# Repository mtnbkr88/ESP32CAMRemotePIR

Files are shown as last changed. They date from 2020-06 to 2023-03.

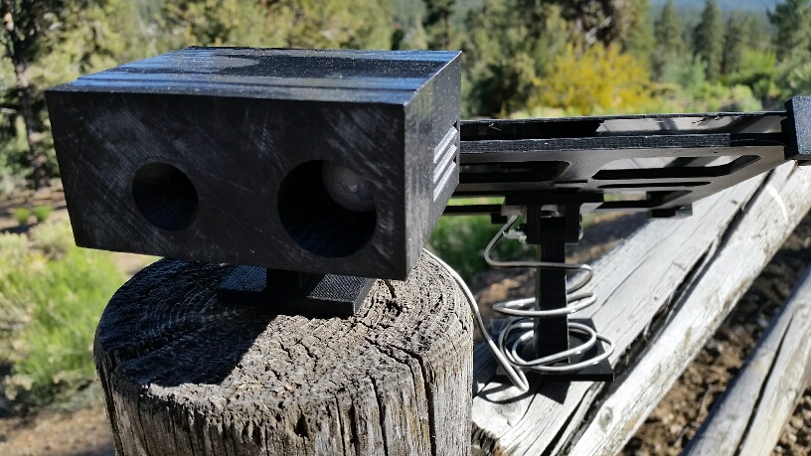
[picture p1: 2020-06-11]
ECRP_Enclosure.jpg

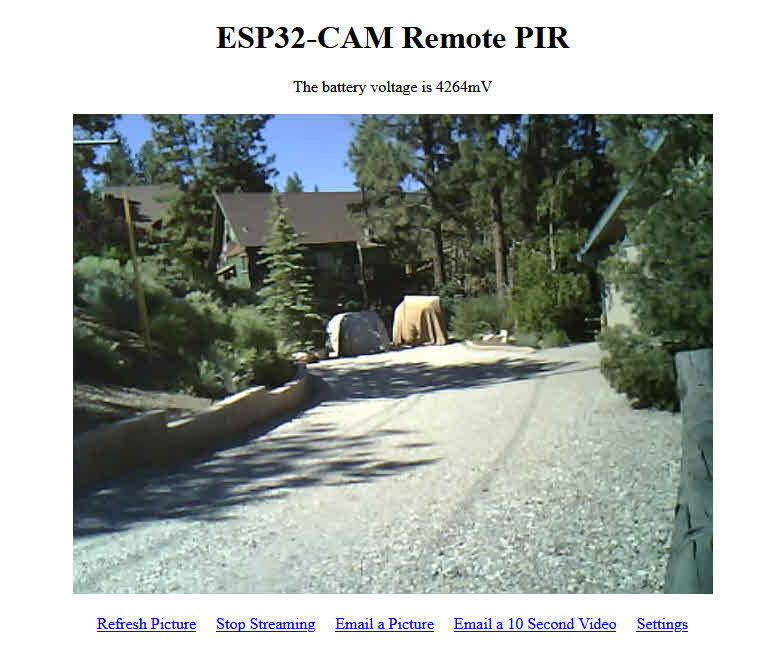
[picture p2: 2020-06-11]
ECRP_Main.jpg

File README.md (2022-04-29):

# ESP32-CAM_Remote_PIR

ESP32-CAM Remote PIR Solar Powered Picture/Video Emailer

04/28/2022 Ed Williams 

This ESP32-CAM Remote PIR can work independent or in conjunction with the ESP32-CAM Video 
Recorder I also posted in github. This ESP32-CAM Remote PIR has the following capabilities:
  - Wake from PIR and do the following:
    - Optionally send a remote trigger to an ESP32-CAM Video Recorder with the following options:
      - Take a picture.
      - Take a picture and email it.
      - Make a video.
      - Make a video and send an email with name of video.   
    - Optionally email up to 6 pictures or a 10 second AVI video.
    - Go to deep sleep.
  - Wake from a time trigger and do the following:
    - Optionally email one picture.
    - Run a webserver for 10 minutes with the following options:
      - Refresh image.
      - Start/Stop a video stream
      - Email a picture or a 10 second video.
      - Access settings.
  - Firmware updates Over-The-Air.
  - No SD card required.
  - Solar powered using a single 18650 battery per the attached schematic.
  - Battery voltage indicator is connected to GPIO12.
  - PIR motion sensor is connected to GPIO13.
  - Pictures are JPG and videos are AVI.
  - Uses a simple email utility I enhanced to send buffers or files which embedded in this
    sketch and is also now found on github. 

See ECRP_Schematic.jpg for a picture of the wiring.

Used pinMode(GPIO_NUM_13, INPUT_PULLDOWN) in the setup to pull the pin low. Now when 
motion is detected, GPIO13 will be pulled high, otherwise it will be low.

ECRP_Main.jpg shows the main screen for the ESP32-CAM Remote PIR web site.

ECRP_Settings.jpg shows the settings page.

I 3D printed an enclosure and bracket for holding the solar panel. ECRP_Enclosure.jpg 
shows the completed project.

The Default Partition Scheme must be used for compiling so OTA can work.

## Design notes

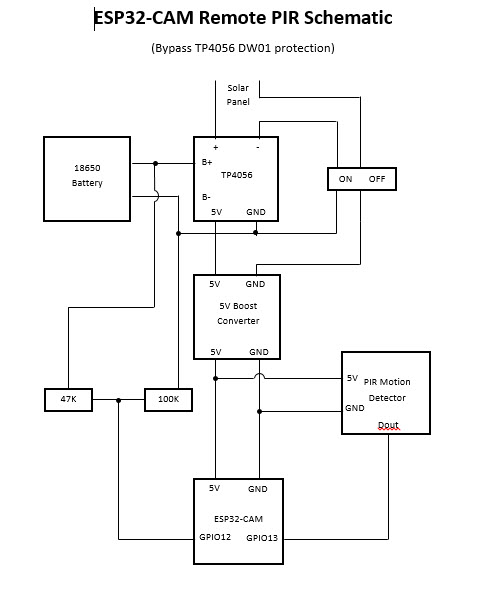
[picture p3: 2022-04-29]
ECRP_Schematic.jpg

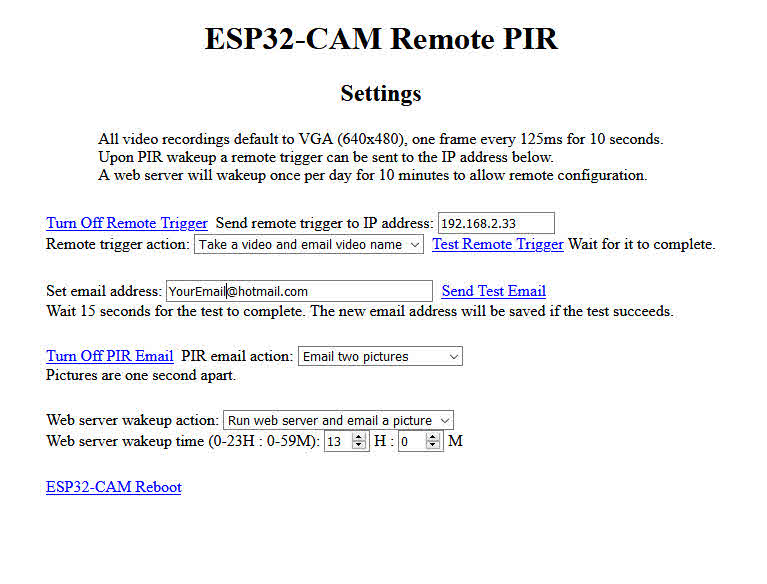
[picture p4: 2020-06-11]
ECRP_Settings.jpg

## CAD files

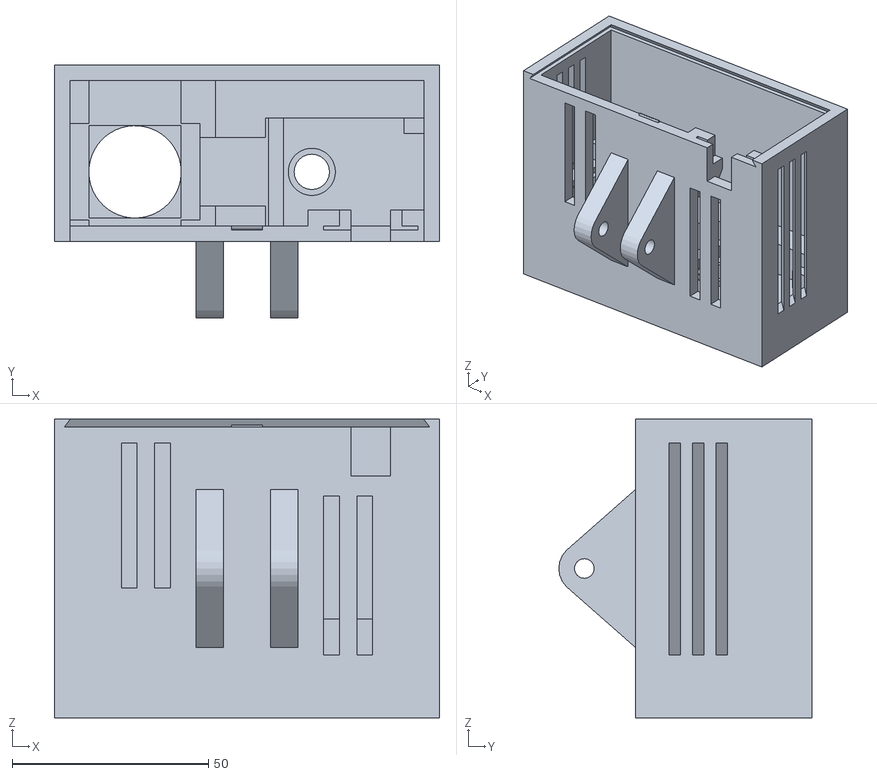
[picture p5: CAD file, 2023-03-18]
ESP32CAM_Box_PIR_Battery.stl
98.0 x 64.5 x 76.0

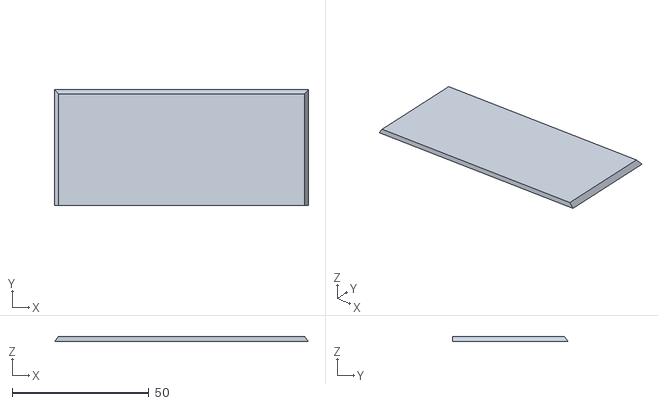
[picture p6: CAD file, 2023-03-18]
ESP32CAM_Box_PIR_Battery_Cover.stl
92.8 x 42.2 x 2.00

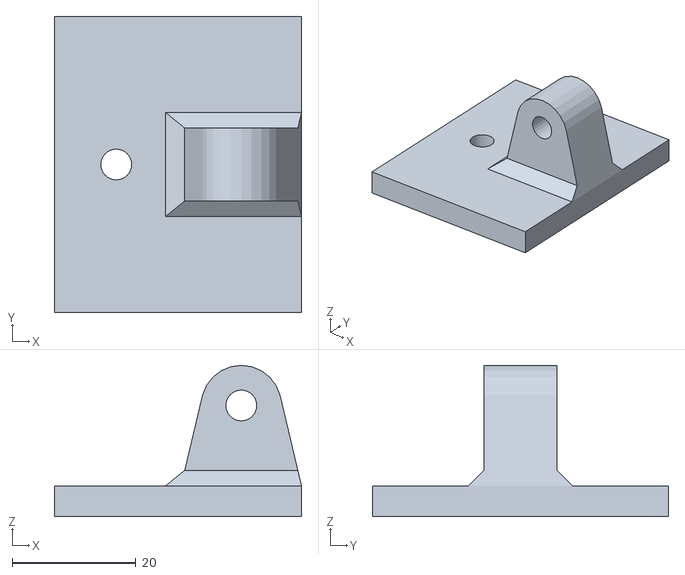
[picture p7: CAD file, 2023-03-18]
ESP32CAM_Box_PIR_Battery_Base.stl
40.0 x 48.0 x 24.5

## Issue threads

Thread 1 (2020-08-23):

webserver wake up time setup  issue

mrmate2, 2020-08-23:
Good day, many thanks for such usefull application.
For testing purposes I am running esp32cam from power adapter, no battery yet.
I am not able to adjust webserver wake up time, its always 99h99m. figures are changing,but immediately they revert to 99h99m
By the way, what is the practical use of such webserver behavior,to save battery power?

mtnbkr88, 2020-08-24:
Hi mrmate2,
I'm glad you find my application useful. My code is out there as a starting point for anybody to modify to their hearts content.

I have not had any issues with any of my four ESP32CAM boards keeping the set wake up time. Here are a few things for you to look at. 1) I use Windows 10 and Firefox browser to access my ESP32CAMs. I have not tried any other browsers. If you are not using Firefox, maybe your browser is not communicating the wake up in a way the webserver on the ESP32CAM expects. Are you seeing the confirmation popup that the wake up time was changed and does it have the correct value? 2) The subroutine where this is handled is called settings_handler. Put some Serial.println statements in there to verify the new wake up time info is getting back to the ESP32CAM. 3) Is it saving other values you are setting? 4) On line 93 of the code the default initial value for the wake up time is set to 1300 (1 pm) Pacific Time in the US. Do you see this initial time after a fresh firmware upload? If not, clear the flash to remove any leftovers from other firmware uploads before doing this firmware upload so the default initial values get loaded.

My ESP32CAMs each run off of one 18650 battery that is charged with a small solar panel and they are placed around my property. They are coded to deep sleep and wake only if the attached PIR detects motion or at the one specified wake up time so I can do maintenance like looking at what it sees or remotely uploading new firmware. This behavior is necessary to save battery power. If you don't need this behavior, change your copy of the code so it never times out to go to deep sleep.

Feel free to download and modify your own copy of this code any way you want, but please don't modify my code here (I'm not sure if you can or can't). I'm using this repository as a place to store my own code and to share it with others who might be interested in a starting point for their projects.

Thanks and good luck.

mrmate2, 2020-08-24:
Appreciate for Your detailed reply.
As per yoyr advise, I cleared the flash to remove any leftovers from other firmware uploads before doing this firmware upload so the default initial values get loaded, and now all is fine!!! I can set time for this option without issues.
Would like to ask You additional questions:
1) in what line and which parametr exactly do I have to change in order to set different timezone?
2) )in what line and which parametr exactly do I have to change in order to cancel deepsleep and to enable webserver run constantly?
Many thanks for Your replies and patience.
Best regards from Ukraine.

mtnbkr88, 2020-08-24:
1) The timezone is set with the TZ_INFO constant on line 42. Since you are in Ukraine I'm going to guess you change "PST8PDT,M3.2.0/2:00:00,M11.1.0/2:00:00" to something like "EET-2EEST,M3.5.0/3:00:00,M10.5.0/4:00:00".

2) In the loop() subroutine, comment out lines 2752-2754 so do_deep_sleep() is never called.

mrmate2, 2020-08-24:
Great! code in line 42 changed.
Remaining 1 step for me to be happy,but while compilation I am getting first error:
                               expected unqualified-id befofe "if"
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

mtnbkr88, 2020-08-24:
You commented out only two lines of the if statement. You need to comment out the third line with the curly bracket to hide the whole if statement.

mrmate2, 2020-08-24:
Yes, You are  right. noticed the same and updated my previous post few minutes fefore Your kind reply.
Now testing how all works.
Many thanks again!! All the best!

mrmate2, 2020-08-24:
Unfortunately,after modifying timezone settings and disabling deepsleep, all functions are working as usuall, exept photo/video alert on PIR motion detected. It is not a surprise due to :

>  Upon start this sketch will check if start was from a PIR signal or the deep
 * timer/power on/reset).
 *
 * If wakeup was from the PIR this sketch will send a remote trigger command to the
 * remoteTriggerIP then, based on settings, take and email pictures or take and
 * email a short video. Then it will go into a deep sleep.
 * If wakeup was from the deep sleep timer/power on/reset then start a web server
 * for 10 minutes to allow changing configuration settings or update firmware.
 * Then it will go into a deep sleep.

so it means : no deep sleep-no wake up and PIR alert....
Seems I will undo my changes in the code and use original version, as absence of PIR alert makes camera no more usefull as security detection device.
Luckily, https://github.com/mtnbkr88/ESP32CAMVideoRecorder is nearby!
Apprreciate Your work done, time spent and advices given!

mtnbkr88, 2020-08-24:
The ESP32CAMRemotePIR code is for an ESP32CAM running off of solar power so it sleeps most of the time. The ESP32CAMVideoRecorder code is for an ESP32CAM that is plugged in all the time, so that is the better choice for you. It's web server will always be on. Don't forget to configure its network, email and timezone info for you and clear your flash before putting this new image on. Note: the ESP32CAMVideoRecorder requires a mini SD card (any size) so it has a place to store pictures and videos. You will be able to view, download or delete these through the web site.

Closed 2020-08-24.

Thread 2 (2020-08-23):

send photo/video to Telegram messenger instead of emailing

mrmate2, 2020-08-23:
Dear author, is it difficuilt for  You to apply such functionality: send photo/video to Telegram messenger instead of emailing or parallel with emailing?
Many thanks in advance!

mtnbkr88, 2020-08-24:
I don't know what a Telegram messenger is, but if its something that can be reached through the internet, then I expect it can be done. Aside from the ESP32CAMs often failing to start the camera when its hot outside, I've got these things working good enough to meet my needs and I've moved on to other things. You are free to download code and add this functionality if you want. It would be a good learning experience for you. That's how I learned. I started with something that was close to what I wanted. I figured out how it worked, then I modified it to do what I wanted.

Good Luck and have fun. These ESP32CAMs are for fun and entertainment. They are too flaky to be used for anything critical.

mrmate2, 2020-08-24:
>  These ESP32CAMs are for fun and entertainment. They are too flaky to be used for anything critical.

That is completely true!!!!!

Closed 2020-08-24.

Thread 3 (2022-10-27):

Power consumption and safety

Patsjemoe, 2022-10-27:
Hi,
Interesting article.
1) have you measured power consumption of the total/how long does your battery lasts ? I have just started a similar project, and seems to drain the battery fast, even when putting esp32 in deep sleep. I suspect the dc dc , but need to check.
2) in your battery schematic, you bypass the dw01 protection ...why would you do that , you create a risk to blow up the battery..?
Thanks in advance
Regards
Ludo

mtnbkr88, 2022-10-27:
Hi Ludo,

1. Yes, the DC-DC boost converter I use does have a 3mA draw when the PIR is in its monitoring mode and ESP32 is in deep sleep. My setup will go a few days with no sun before the battery runs out which has not been an issue since I always have lots of sun.

2. If the dw01 protection is in circuit, when I switch on the power the dw01 thinks there's an issue and it shuts off the output. Then I have to temporarily short the battery negative to the dw01 negative to make it work. I'm not willing to deal with that so I bypass the dw01. I'm not worried about blowing up the battery. Feel free to wire that part to include the dw01 protection in your circuit. Hopefully you'll have better luck with it starting correctly. It's possible that newer TP4056 boards have resolved the shutoff on power on issue.

My setup has been working fine for years. Thanks for your interest.

Ed

mtnbkr88, 2022-10-28:
I used this one: https://www.ebay.com/itm/401149613381

-------- Original message --------
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

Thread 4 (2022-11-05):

Compilation error : 'ADC2_GPIO12_CHANNEL' was not declared in this scope

Patsjemoe, 2022-11-05:
Hi,
When compiling, I get following error :
'ADC2_GPIO12_CHANNEL' was not declared in this scope
   adc2_config_channel_atten(ADC2_GPIO12_CHANNEL, ADC_ATTEN_11db);
Any suggestions ?
regards
Ludo

Patsjemoe, 2022-11-05:
Hi Ed,
In the comiler, it suggested to use ADC2_CHANNEL_9 instead of ADC2_GPIO12_CHANNEL....using this, the compile error disappeared, but now the camera does not initialize.
E (3057) ledc: ledc_stop(661): LEDC is not initialized
E (3097) camera: Camera probe failed with error 0x105(ESP_ERR_NOT_FOUND)
Camera init failed with error 0x105, trying again...E (3197) gpio: gpio_install_isr_service(449): GPIO isr service already installed
It seems difficult to find information on which channel to use for ESP32CAM. The only info I found was channel 5, but then it give a fatal core error.
Any suggestions ?
Regards
Ludo

mtnbkr88, 2022-11-05:
Hi Ludo,
My research says ADC2_GPIO12_CHANNEL is defined in soc/adc_channel.h which my Arduino environment appears to be finding. In adc_channel.h is:
#define ADC2_GPIO12_CHANNEL     ADC2_CHANNEL_5
You didn't tell me the fatal error that gives.
The program I posted compiles and works fine in my environment which is Arduino 1.8.15 and in the Boards Manager I'm using esp32 version 1.0.2 (not any of the newer versions). Try that configuration and let me know if it works.

Patsjemoe, 2022-11-05:
Hi Ed,
Thank you for your feedback.
 I do not find adc_channel.h in your file as #include.... Shouldn't that
be? This may be the reason of my first error...?
I will retry tomorrow and confirm error.
Regards
Ludo

Op za 5 nov. 2022 21:54 schreef mtnbkr88 ***@***.***>:

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

mtnbkr88, 2022-11-06:
Hi Ludo,
I did not explicitly include adc_channel.h. The .ino file I uploaded is the file I used. I think the esp32 v1.0.2 configuration I use as described above automatically pulls in ADC2_GPIO2_CHANNEL. Other esp32 versions or other Arduino versions may behave differently.
Ed

Patsjemoe, 2022-11-06:
Hi Ed,
Including soc/adc_channel  no longer gives an error, it compiles fine.
It starts up , connects to internet, wakes up bij timer ,until config
camera..then it goes wrong.

Loading initial values from EEPROM

Remote trigger set to 0

Remote IP address set to 0.0.0.0

Email address set to ***@***.***

Motion email action set to 1

Wakeup Time set to 11300

Wakeup caused by timer, power on, or reset - starting config web server

 Before startWebServer  Free Heap: 202992

 After startWebServer  Free Heap: 180764

config camera

 Before camera init  Free Heap: 180564

*E (3132) ledc: ledc_stop(661): LEDC is not initialized
*

*Pic, len=10346
*

*Guru Meditation Error: Core  1 panic'ed (LoadProhibited). Exception
was unhandled.*

Core  1 register dump:

PC      : 0x400d349f  PS      : 0x00060c30  A0      : 0x800d3460  A1
   : 0x3ffb20d0

A2      : 0x3ffc4ad8  A3      : 0x3ffc4994  A4      : 0xfffffffe  A5
   : 0x00000000

A6      : 0x3ffcf220  A7      : 0x3ffc498c  A8      : 0x3ffc498c  A9
   : 0x3ffb2090

A10     : 0x00000021  A11     : 0x00000000  A12     : 0x00000000  A13
   : 0x00000000

A14     : 0x3ffcf220  A15     : 0x00000000  SAR     : 0x00000007
EXCCAUSE: 0x0000001c

EXCVADDR: 0x00000002  LBEG    : 0x4008d5d5  LEND    : 0x4008d5e5
LCOUNT  : 0xfffffffe

Backtrace:0x400d349c:0x3ffb20d00x400d345d:0x3ffb2100
0x400d473f:0x3ffb2120 0x400d5a99:0x3ffb21b0 0x400d63a1:0x3ffb27b0
0x400d6e58:0x3ffb27d0 0x400df8ae:0x3ffb2820

note : with esp32 version 1.0.2 installed, I get following error :
Error resolving FQBN: getting build properties for board
esp32:esp32:esp32cam: invalid option 'CPUFreq'

Compilation error: Error resolving FQBN: getting build properties for board
esp32:esp32:esp32cam: invalid option 'CPUFreq'
Compilation error: Error resolving FQBN: getting build properties for board
esp32:esp32:esp32cam: invalid option 'CPUFreq'

regards
Ludo
I:\arduino\hardware\espressif\esp32\sketches\esp32camPIRemail\esp32camPIRemail.ino:
In function 'esp_err_t start_avi_buf()':
I:\arduino\hardware\espressif\esp32\sketches\esp32camPIRemail\esp32camPIRemail.ino:904:1:
warning: no return statement in function returning non-void [-Wreturn-type]
 } // end of start avi

Compilation error: Error resolving FQBN: getting build properties for board
esp32:esp32:esp32cam: invalid option 'CPUFreq'

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

mtnbkr88, 2022-11-06:
Ludo,
There is definitely a difference between your environment and mine. I had trouble with ESP32 versions higher than 1.0.2 so I didn't use them. I used ESP32-CAM boards based on AI thinker. Here are my settings in Arduino.

    - Go to Tools->Board->Boards Manager....
    - Search for ESP32 and press Install button for "ESP32 by Espressif Systems". (Use version 1.0.2)
    - Go to Tools->Board->ESP32 Wrover Module.
    - Upload Speed "921600"
    - Flash Frequency "80MHz"
    - Flash Mode "QIO"
    - Partition Scheme "Default 4MB with spiffs" or "Default 4MB with ffat"
      either one should support firmware builds up to 1.3MB and OTA
    - Core Debug Level "None"
    - Port "COM6" - can only set this after FTDI adapter is plugged in USB
      (When using the serial monitor, set its baud rate to 115200)

mtnbkr88, 2022-11-06:
I also installed an ESP Exception Decoder. This will allow you to find the line in your code that is giving an exception.
Find and download the EspExceptionDecoder.jar from the internet and install as follows:
    - Create folder C:\Users\Owner\Documents\Arduino\tools\EspExceptionDecoder\tool.
    - Place EspExceptionDecoder.jar in it.
    - Restart Arduino IDE. ESP Exception Decoder can now be found under Tools.
If an exception occurs, copy the trace dump and paste it into the ESP Exception Decoder window and it
will give more clues for what went wrong.

mtnbkr88, 2022-11-06:
If you haven't already, you might want to install a basic ESP32 camera example test program from the examples area of Arduino or EspressIf to be sure your board and camera work correctly before trying my program which is more complex.

Patsjemoe, 2022-11-06:
Hi Ed,
I had done this already, but could not use it yet due to the errors.
I tried to install it in version 2.0, but it only works with 1.18 due to
java....
regards
Ludo

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

Patsjemoe, 2022-11-06:
Hi Ed,
Here I used ESP32cam...changed to ESP32 wrover module.
Partition scheme in version 1.8.15 is different : I took minimal SPIFFS,
large apps with ota...
[image: image.png]
In both your program as well as a basic esp32cam webserver, I had following
error :
xtensa-esp32-elf-g++: error: unrecognized command line option
'-mfix-esp32-psram-cache-strategy=memw'
exit status 1
Error during compilation for  board ESP32 Wrover Module
Looking further into it...
regards
Ludo

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

Patsjemoe, 2022-11-06:
Hi Ed,
I wonder if there is a conflict between different installed versions./..

regards
Ludo

On Sun, 6 Nov 2022 at 19:52, Ludo Kustermans ***@***.***>
wrote:

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

Patsjemoe, 2022-11-06:
Hi Ed,
....sorry for hte many mails....
I had installed version 1.02, but it seems you need to do also an update
....now I can select the right
Default 4MB with spiffs
Still errors....but moving forward...
regards
Ludo

On Sun, 6 Nov 2022 at 19:52, Ludo Kustermans ***@***.***>
wrote:

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

mtnbkr88, 2022-11-06:
Glad you are making progress. I don't think the example camera program worked for me the first time either. Like I said, work on getting the example camera program working. Once you get that working it should be simple to get my program working. My program uses OTA for firmware updates so you will need to choose a partition scheme that supports OTA. I don't use spiffs so your choice if you want to allocate space for spiffs.

Patsjemoe, 2022-11-07:
Hi Ed,
Did a new clean install of 1.8.15 with espressif 1.0.2, and it works
now 😀....touch wood it will
stay that way .
I must admit, when seeing soo many errors yesterday, it made me feel like
it would never work....
WIth the installation of 1.8.15, I then had also issues with my arduino 2.0
version, but it seems that the espressif board version 1.02 that I
installed, also is installed in the version 2.0...I am not sure if there is
a way to be sure the version remains only in the arduino version where you
install it....
Ludo

Op zo 6 nov. 2022 22:29 schreef mtnbkr88 ***@***.***>:

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

Patsjemoe, 2022-11-07:
Hi Ed,
From the Arduino forum I received following : (was not 100% sure...).
1.8.15 has the log4j security vulnerability; you're advised to upgrade to
1.8.19 or go back a few to before 1.8.13
Just that you know it may have an issue...
regards
Ludo

On Mon, 7 Nov 2022 at 12:07, Ludo Kustermans ***@***.***>
wrote:

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

mtnbkr88, 2022-11-07:
Hi Ludo,
I very happy to hear you got it working. I'm not losing any sleep over security vulnerabilities in my ESP32 projects. Thanks for letting me know. If you install Arduino 1.8.19 with espressif 1.0.2 and get it working please let me know.
Enjoy!
Ed

Patsjemoe, 2022-11-07:
Hi Ed,
I tested with arduino 1.8.19 and espressif 1.0.2 and it worked well.
Just 1 more question : I saw that you connect directly the output of the
pir (5V) to the esp32cam. It is difficult to find a datasheet
showing if the GPIO pins are 5V tolerant.....you never had any issue ? Or
did you get confirmation that they are 5V tolerant ?
I can also change to a 3.3V level with a transistor, levels are then
reversed....this is also OK, but have to change also the
conditional checks on the level op GPIO13 further in the program...how many
places should I find ?
regards
Ludo

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

mtnbkr88, 2022-11-07:
Hi Ludo,
Glad to hear Arduino 1.8.19 and espressif 1.0.2 are good.
I've been running my PIR setup for years and there is definitely no issue with using the 5V out from the PIR. For a while I did use a transistor between the PIR and ESP32 but it did not work well. Also, the PIR I use is HC-SR501. I had a lot of problems with false positives but after much research I found that putting a 220nF capacitor between pins 12 and 13 on the main chip as shown here (https://redfox314.tweakblogs.net/blog/16895/esp8266-and-hc-sr501-false-positives) solved it. My solar setup has been rock solid sitting on top of a fence post watching my driveway for years.
Ed

Closed 2022-11-05.

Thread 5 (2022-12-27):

time for webserver to run

Patsjemoe, 2022-12-27:
Hi Ed,
I would like the time the server runs to bring back to 1 min (or even zero to save power, and only email pictures when moving).
  if ( millis() - timeout_10min > (10 * 60 * 1000) ) {
    do_deep_sleep();

I changed it to :
  if ( millis() - timeout_10min > (1 * 60 * 1000) ) {
                                                   -- > so I expected 1 min
but it does not go asleep after 1 min...
Any suggestions to what I do wrong  ?
Thanks in advance
regards
Ludo

Patsjemoe, 2022-12-27:
Hi Ed,
When I change to if ( millis() - timeout_10min > (1 * 60 * 100) ) {
...it goes asleep after 6-7 sec...which is accordingly..
Not sure why , do not understand
regards
Ludo

Patsjemoe, 2022-12-27:
Hi Ed,
I used different cams for the 2 tests, with 1 device, it works , with the other one, it is not going to sleep.....if someone understands this ?
Regards
Ludo

Patsjemoe, 2022-12-27:
Hi Ed,
You can forget the question, but want to share this issue, as it is simple, but at the same time difficult to find.
I adapted from PIR to detection when a switch opens, with a pulldown resistore external, so would be triggerd with 3V on pin 13.
When I adapted my program to 1 minute, it did not work, as there was in fact a constant trigger from the switch that was at 1 (in my application, it is pushed down to give a 0, and gives a 1 when the roof of the squirl feeding house opens, but as I was working on it, the roof was constantly open...) It works fine now, testing how long it works on battery....

mtnbkr88, 2022-12-27:
Glad you got it working for a detector for when a squirrel opens his nut house. For your first question change the math to (6 x 1000) and you'll understand. millis() gives a value in milliseconds. 1000 milliseconds is one second. So 6 x 1000 is 6 seconds.

Closed 2022-12-27.

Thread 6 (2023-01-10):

Re-wake up

Patsjemoe, 2023-01-10:
Hi Ed,
When setting  the daily  wake time to 6 seconds (save power) ,It makes a multiple wake up from 2 to 4 times. Any idea why that can be?
Regards
Ludo

mtnbkr88, 2023-01-10:
Hi Ludo,
I'm not exactly sure what you mean by setting the daily wake time to 6 seconds. If you didn't change it the wake time is one specific time of day. The deep sleep logic calculates how long from current time to the daily wake time specified in your settings and uses that to set how long to sleep. If it wakes multiple times a day there is something wrong with the logic you are using to calculate how long to sleep.
Ed

Patsjemoe, 2023-01-11:
Hi Ed,
It is the time it stays awake... 6 sec.
When it wakes up hasn't changed, 1x a day.
But it wakes up 2-4 times in a period of 1-2minutes, often it sends a photo
with the same wakeup time.
When setting time to 10 minutes, it is only once.... I wonder what triggers
this multiple wake up. Could you try yourself and see what happens?
Regards
Ludo

Op di 10 jan. 2023 22:00 schreef mtnbkr88 ***@***.***>:

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

mtnbkr88, 2023-01-11:
If it fails to get a network connection it will sleep for a second and wake to try again. If it has trouble initializing the camera which happens often with mine it will retry again up to five times. If it thinks it failed to send the email it will retry sending the email multiple times. If you are using a PIR sensor that is too sensitive it can trigger often with false alarms. Mine goes crazy when it rains. Plus I don't know how you've modified the code. There are so many areas of possible trouble that I'm afraid there isn't one specific thing I can say is causing your issue.

Mine is normally sitting on a fence at the limits of my local wifi network. It's often having problems and when I bring it in and connect it to my laptop to watch the serial monitor it works better so I'm having difficulties with its inconsistent behavior. I'm still tweaking my code trying to make it work better but it never gets better. Unfortunately these little ESP32CAMs are not very reliable and probably should be considered as toys. It is what it is.

All I can suggest is to connect it to a serial port, put lots of Serial.println statements in areas you think might be where the problem is and watch the serial monitor for a while in hopes of capturing any clues to your issue.

Sorry I can't help more.
Good Luck!

Patsjemoe, 2023-01-11:
Hi Ed,
Thank you, so these retries are normal, depending the circumstance.....this
is clear. I also understand now where the 1 sec is used for... Was
wondering...

What I also observed... when the "10 min" server is active, I do not get
reaction to my PIR... Is this normal?

FYI  : I changed my esp32cam to take an external antenna, which I need, as
it also stands away from my house... This gives better results.

Thank you for your quick reply.

Regards
Ludo

Op wo 11 jan. 2023 08:47 schreef mtnbkr88 ***@***.***>:

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

mtnbkr88, 2023-01-11:
Hi Ludo,

I put an up to 10 min wait for the PIR signal to stop when going to sleep to prevent continuous quick triggers. For me if too many emails are sent too quickly gmail locks my email account. I'm trying to prevent that. I'm sure you know you can change the code to do anything you want.

I've thought about adding an external antenna but I don't want to.

Ed

Closed 2023-01-10.

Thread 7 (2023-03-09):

cant compile

allbondy, 2023-03-09:
it is most like me
but cant work it out
help would be greatly appreciated

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

mtnbkr88, 2023-03-09:
ADC2_GPIO12_CHANNEL is defined as part of esp32 library version 1.0.2. In Arduino IDE (I'm using version 1.8.15), go into Tools->Board: "ESP32 Wrover Module"->Boards Manager... . In the search bar at the top, search for esp32. When esp32 library is found, set the version to 1.0.2 then pick Install. This should solve your issue.

Closed 2023-03-09.

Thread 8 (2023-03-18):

3D Print Enclosure

gwinterhalter, 2023-03-18:
Hi mtnbkr88

Can you add the Cad/Stl files for enclosure?

Great work on this project. Intend to build a couple.

Thanks Greg

mtnbkr88, 2023-03-18:
Done - good luck with your builds.

Closed 2023-03-18.

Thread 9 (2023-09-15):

Guru Meditation Error: Core  1 panic'ed

Patsjemoe, 2023-09-15:

Patsjemoe, 2023-09-15:
trying few more things, therefore actually closed

mtnbkr88, 2023-09-15:
Hi Ludo,

I'm still using Arduino 1.8.15 and board version 1.0.2.
Install the attached EspExceptionDecoder.jar using the instructions below. Paste the backtrace from the error in the tool and it will tell you what line in the code is giving the error and a clue as to why.
    - Create folder C:\Users\Owner\Documents\Arduino\tools\EspExceptionDecoder\tool.
    - Unzip EspExceptionDecoder.zip and place EspExceptionDecoder.jar in the directory create above.
    - Restart Arduino IDE. ESP Exception Decoder can now be found under Tools.

[EspExceptionDecoder.zip](https://github.com/mtnbkr88/ESP32CAMRemotePIR/files/12622438/EspExceptionDecoder.zip)

Patsjemoe, 2023-09-15:
Hi there,
It's been a while... 😃. Hope you are OK.
I first had put in the back trace, but took it out, because I thought it
was because for whatever reason the board version updated. Went back to a
clean 1.02.
Now I do not get the panic error anymore, but with 1.0.2 waiting in email
picture, and moving to 1.0.5, it says waiting in email picture, failed to
send, end of setup, esp ready, so it goes further.
I can go onto the server.
Trying to figure out why it does not send the mail.... Should  be OK, as I
am running 2 other birdhouses.... But it is not.
Best regards
Ludo

Op vr 15 sep. 2023 20:12 schreef mtnbkr88 ***@***.***>:

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

mtnbkr88, 2023-09-15:
Hi Ludo,
When I tried board versions higher than 1.0.2 I got errors so I just stuck with 1.0.2. Your issue is a mystery. Did you try a different board with the exact same code to verify it's not a hardware issue? Did you add any other code that is using up heap? I found that lots of heap needs to be available for network stuff to work. Maybe put some print statements that show the heap before, during, and after the email to see if its a low memory issue.

mtnbkr88, 2023-09-15:
Search for //#define DEBUG_EMAIL_PORT (around line 460 in my copy of the code), uncomment this line (remove two slashes), then recompile and run again. You should see debug info for the sending email part. Hopefully there will be a clue in there as to why the email is failing to send.

Patsjemoe, 2023-09-16:
Hi,
Thanks for yr suggestion, did not know it was in there .
Connecting: smtp.gmail.com:465
Connecting: smtp.gmail.com:465
Connecting: smtp.gmail.com:465
Connecting: smtp.gmail.com:465
Connecting: smtp.gmail.com:465
Failed to send email
It must have to do with my app password...made a new one, but still a
problem...look further.

Stil not working after a whole day, so any idea is welcome.
Had 2 other birdhouses working, nothing changed, so I am puzzled.
Since I had to change my psw, it also deletes all app psw in Google, so
made new ones..... Surprised that google has no tool to quickly check app
password...

regards
Ludo

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

mtnbkr88, 2023-09-16:
Hi Ludo,
Based on your message above it sounds like you are using an app password for sending your email which is what I had to do last year.

The output you posted shows its failing it's first connection to the gmail server. Look for the below in your code and add the lines with "//*** add for debug" in them to hopefully see why the connection is failing:

#ifdef DEBUG_EMAIL_PORT
  Serial.print(F("Connecting: "));
  Serial.print(host);
  Serial.print(":");
  Serial.println(port);
#endif
  if (!client->connect(host.c_str(), port))
  {
#ifdef DEBUG_EMAIL_PORT                  //*** add for debug
    String buffer = readClient();              //*** add for debug
    Serial.print(F("SERVER->CLIENT: "));  //*** add for debug
    Serial.println(buffer);                        //*** add for debug
#endif                                                 //*** add for debug
    return false;
  }
  String buffer = readClient();

If that doesn't work, to hopefully see what code client->connect(host.c_str(), port) is returning replace:

 if (!client->connect(host.c_str(), port))

with:

 int clientReturnCode;
 clientReturnCode = client->connect(host.c_str(), port));
 Serial.print(F("clientReturnCode: "));
 Serial.println(clientReturnCode);
 if (!clientReturnCode)

Look in https://github.com/espressif/newlib-esp32/blob/master/newlib/libc/include/sys/errno.h
to see what the clientReturnCode means.

I have had the problem where my ESP32 chips have sent too many emails to gmail and they blocked login from my ESP32 thinking it was spam. Waiting a day unblocked the account.

Below are my notes from when I had to switch to using an app password for my esp32 stuff in case it helps.

NOTE: Around 06/07/22 gmail made changes that broke my sendmail stuff. I had to do the
following to create another gmail account and use a 2-factor app password:
- Create another gmail account so if it gets messed up it doesn't screw my normal gmail
  account.
  - Go to https://www.google.com/gmail/about/.
  - Pick Create an account.
  - First: <private>, Last: ESP32, Username: <private>ESP32@gmail.com, PW: usual
  - Recovery email: <private>@gmail.com, bday, gender
- Create an App Password to use with the new gmail account.
  - Open the google account. https://myaccount.google.com/u/1/?hl=en
    (Make sure its for <private>ESP32@gmail.com and not my other gmail address.
  - In navigation panel, select Security.
  - Under "Signing in to google", select 2-Step Verification->Get started.
  - Follow prompts to complete 2-step verification.
  - Back to google account page, select Security again.
  - Under "Signing in to Google", select App Passwords.
  - Set Selected app to mail, and selected device to Other and set its name to ESP32,
    Generate. Copy the 16 char password to use as the password later: <app_pw>
- Yay, its working with <private>esp32@gmail.com and the password above. Use these
  for future emails from my esp32 chips.

Good luck!
Ed

Patsjemoe, 2023-09-17:
Hi,
You showed :
Set Selected app to mail, and selected device to Other and set its name to
ESP32,
I did not see anything to assign to mail, only to delete it.
Will check again...
Not sure how, right click?
Regards
Ludo

Op zo 17 sep. 2023 01:20 schreef mtnbkr88 ***@***.***>:

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

Patsjemoe, 2023-09-17:
Hi,
after first replacement : 5x
Connecting: smtp.gmail.com:465
SERVER->CLIENT:

after second replacement (clientReturnCode = client->connect(host.c_str(),
port);
Connecting: smtp.gmail.com:465
clientReturnCode: 0 ---> did not find this code
SERVER->CLIENT:
Regards
Ludo

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

Patsjemoe, 2023-09-17:
Hi,
I moved back (again) to 1.0.2 , and now it works again....
I am not sure what is happening, but will just be glad it works.
Still, In Gmail, I cannot select App PSW in security google login, but need
to go to 2 step verification and then go to
app.....but cannot select /assign the password to some application....I do
not have a dropdown menu. Try google to get response on this...
Thanks again for your attention and help.
regards
Ludo

On Sun, 17 Sept 2023 at 09:16, Ludo Kustermans ***@***.***>
wrote:

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

mtnbkr88, 2023-09-17:
Glad it works again. My notes are from over a year ago so its likely Google change something since then. FYI - A return code of 0 means there was no error and it should have worked correctly.

Good luck,
Ed

Closed 2023-09-15.

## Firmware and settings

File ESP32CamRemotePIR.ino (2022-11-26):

/**********************************************************************************
 * 11/25/2020 Edward Williams
 * Upon start this sketch will check if start was from a PIR signal or the deep 
 * timer/power on/reset).
 * 
 * If wakeup was from the PIR this sketch will send a remote trigger command to the 
 * remoteTriggerIP then, based on settings, take and email pictures or take and 
 * email a short video. Then it will go into a deep sleep. 
 * 
 * If wakeup was from the deep sleep timer/power on/reset then start a web server 
 * for 10 minutes to allow changing configuration settings or update firmware.
 * Then it will go into a deep sleep.
 * 
 * A battery divider circuit with a 147K and 100K resister will be attached to GPIO12
 * for battery voltage reads. A PIR detector will be attached to GPIO13 for PIR wakeup
 * from deep sleep.
 **********************************************************************************/


/**********************************************************************************
 * 03/25/2020 Edward Williams
 * This is a shell which includes an Over-The-Air firmware update web server which
 * includes the option to erase EEPROM, fixed IP address, a major fail flashing led 
 * notice with sleep reboot, time set and mount of SD card. I use this as a starting 
 * point for all my sketches. Visit the web site <IP>/updatefirmware and enter the 
 * password to upload new firmware to the ESP32. Compile using the "Default" Partition 
 * Scheme.
 **********************************************************************************/
 
// edit the below for local settings 

// wifi info
const char* ssid = "YOURSSID";
const char* password = "YOURSSIDPW";
// fixed IP info
const uint8_t IP_Address[4] = {192, 168, 2, 35};
const uint8_t IP_Gateway[4] = {192, 168, 2, 1};
const uint8_t IP_Subnet[4] = {255, 255, 255, 0};
const uint8_t IP_PrimaryDNS[4] = {8, 8, 8, 8};
const uint8_t IP_SecondaryDNS[4] = {8, 8, 4, 4};

const char* TZ_INFO = "PST8PDT,M3.2.0/2:00:00,M11.1.0/2:00:00";

const int SERVER_PORT = 80;  // port the main web server will listen on

// edit email server info for the send part, recipient address is set through Settings in the app
const char* emailhost = "smtp.gmail.com";
const int emailport = 465;
const char* emailsendaddr = "YOUREMAIL\@gmail.com";
const char* emailsendpwd = "YOUREMAILPW";
char email[40] = "YOUREMAIL\@hotmail.com";  // this can be changed through Settings in the app

const char* appName = "ESP32CamRemotePIR";
const char* appVersion = "1.0.7";
const char* firmwareUpdatePassword = "12345678";

// should not need to edit the below

#include "esp_http_server.h"
httpd_handle_t webserver_httpd = NULL;   

#include <WiFi.h>

#include "soc/soc.h"  //disable brownout problems
#include "soc/rtc_cntl_reg.h"  //disable brownout problems

#include "time.h"
#include "lwip/err.h"
#include "lwip/apps/sntp.h"
struct tm timeinfo;
time_t now;

#include <EEPROM.h>  // for erasing EEPROM ATO, assumes EEPROM is 512 bytes in size
#include <Update.h>  // for flashing new firmware

#define uS_TO_S_FACTOR 1000000LL  // Conversion factor for micro seconds to seconds
#define TIME_TO_SLEEP1S  1        // Time ESP32 will go to sleep (in seconds)

// EEPROM setup for saving values over reboots
#include <EEPROM.h>  // also used in OTA firmware update screen
#define EEPROM_READY_ADDR 0x00
const byte eeprom_ready[] = {0x52, 0x65, 0x61, 0x64, 0x79};
#define EEPROM_REMOTE_ADDR (EEPROM_READY_ADDR+sizeof(eeprom_ready))
int remoteTrigger = 0;  // <10 is off, >10 is on
#define EEPROM_REMOTEIP_ADDR (EEPROM_REMOTE_ADDR+sizeof(remoteTrigger))
char remoteTriggerIP[16] = "0.0.0.0";  // example
#define EEPROM_EMAIL_ADDR (EEPROM_REMOTEIP_ADDR+sizeof(remoteTriggerIP))
// default email defined above
#define EEPROM_MOTIONEMAILACTION_ADDR (EEPROM_EMAIL_ADDR+sizeof(email))
int motionEmailAction = 1;  // < 10 is off, >10 is on
                            // 1(11) to 6(16) send 1 to 6 pictures, 7(17) send video
#define EEPROM_WAKEUPTIME_ADDR (EEPROM_MOTIONEMAILACTION_ADDR+sizeof(motionEmailAction))
int wakeupTime = 11300;  // X div 10000 is send wakeup email (1) or no (0), 
                         // X mod 10000 div 100 is hours, X mod 100 is minutes
#define EEPROM_SIZE_ADDR (EEPROM_WAKEUPTIME_ADDR+sizeof(wakeupTime))

#include "esp_camera.h"
// CAMERA_MODEL_AI_THINKER
#define PWDN_GPIO_NUM     32
#define RESET_GPIO_NUM    -1
#define XCLK_GPIO_NUM      0
#define SIOD_GPIO_NUM     26
#define SIOC_GPIO_NUM     27
#define Y9_GPIO_NUM       35
#define Y8_GPIO_NUM       34
#define Y7_GPIO_NUM       39
#define Y6_GPIO_NUM       36
#define Y5_GPIO_NUM       21
#define Y4_GPIO_NUM       19
#define Y3_GPIO_NUM       18
#define Y2_GPIO_NUM        5
#define VSYNC_GPIO_NUM    25
#define HREF_GPIO_NUM     23
#define PCLK_GPIO_NUM     22

#include <HTTPClient.h>

unsigned long timeout_10min = 0LL;
int PIRActionActive = 0;  // 0 - not waiting for remote trigger, 1 - waiting for remote trigger
RTC_DATA_ATTR int PIRWakeup = 0;   // 0 - wake from restart or timer trigger, greater than 0 is PIR wakeup


//~~~~~~~~~~~~~~~~~~~~~~~~~~~~~~~~~~~~~~~~~~~~~~~~~~~~~~~~~~~~~~~~~~~~~~~~~~~~~~~~~
//
// 

void do_deep_sleep() {  

  // wait up to 600 seconds for PIR trigger event to end
  int loopcount = 0;
  while ((gpio_get_level(GPIO_NUM_13) == 1) && (loopcount < 600)) { 
    delay(1000); 
    if (gpio_get_level(GPIO_NUM_13) == 0) { delay(1000); }
    loopcount++;
  }
  delay(1000);
  
  Serial.println("Going to deep sleep");

  PIRWakeup = 0;
  
  //esp_sleep_enable_ext0_wakeup(GPIO_NUM_X, level)
  esp_sleep_enable_ext0_wakeup(GPIO_NUM_13, 1);

  // turn off wifi
  WiFi.disconnect();

  // setup time wakeup
  time(&now);
  localtime_r(&now, &timeinfo);
  char strftime_buf[64];

  strftime(strftime_buf, sizeof(strftime_buf), "%H", &timeinfo);
  int curTH = atoi(strftime_buf); 
  strftime(strftime_buf, sizeof(strftime_buf), "%M", &timeinfo);
  int curTM = atoi(strftime_buf); 
  int curT = (curTH * 60) + curTM;

  int wakeTH = (wakeupTime % 10000) / 100;
  int wakeTM = wakeupTime % 100;
  int wakeT = (wakeTH * 60) + wakeTM;
  if (curT > wakeT) wakeT = wakeT + (24 * 60);
  wakeT = wakeT - curT;
  Serial.println("Scheduled to wakeup at " + String(wakeTH) + " H : " + String(wakeTM) + " M");
  
  esp_sleep_enable_timer_wakeup(wakeT * 60 * uS_TO_S_FACTOR);

  esp_deep_sleep_start();
}


//~~~~~~~~~~~~~~~~~~~~~~~~~~~~~~~~~~~~~~~~~~~~~~~~~~~~~~~~~~~~~~~~~~~~~~~~~~~~~~~~~
//
// 

void do_deep_sleep_1sec() {  

  // turn off wifi
  WiFi.disconnect();

  esp_sleep_enable_timer_wakeup(TIME_TO_SLEEP1S * uS_TO_S_FACTOR);
  esp_deep_sleep_start();
}


//~~~~~~~~~~~~~~~~~~~~~~~~~~~~~~~~~~~~~~~~~~~~~~~~~~~~~~~~~~~~~~~~~~~~~~~~~~~~~~~~~
//
// 

void major_fail() {  //flash the led on the ESP32 in case of error, then sleep and reboot

  //for  (int i = 0;  i < 5; i++) {
  for  (int i = 0;  i < 1; i++) {
    digitalWrite(33, LOW);   delay(150);
    digitalWrite(33, HIGH);  delay(150);
    digitalWrite(33, LOW);   delay(150);
    digitalWrite(33, HIGH);  delay(150);
    digitalWrite(33, LOW);   delay(150);
    digitalWrite(33, HIGH);  delay(150);

    delay(150);

    digitalWrite(33, LOW);  delay(500);
    digitalWrite(33, HIGH); delay(150);
    digitalWrite(33, LOW);  delay(500);
    digitalWrite(33, HIGH); delay(150);
    digitalWrite(33, LOW);  delay(500);
    digitalWrite(33, HIGH); delay(150);

    delay(150);

    digitalWrite(33, LOW);   delay(150);
    digitalWrite(33, HIGH);  delay(150);
    digitalWrite(33, LOW);   delay(150);
    digitalWrite(33, HIGH);  delay(150);
    digitalWrite(33, LOW);   delay(150);
    digitalWrite(33, HIGH);  delay(150);

    delay(450);
  }

  // sleep for 1 second and restart
  do_deep_sleep_1sec();
}


//~~~~~~~~~~~~~~~~~~~~~~~~~~~~~~~~~~~~~~~~~~~~~~~~~~~~~~~~~~~~~~~~~~~~~~~~~~~~~~~~~
//
// 

bool init_wifi()
{
  int connAttempts = 0;
  
  // this is the fixed ip stuff 
  IPAddress local_IP(IP_Address);

  // Set your Gateway IP address
  IPAddress gateway(IP_Gateway);

  IPAddress subnet(IP_Subnet);
  IPAddress primaryDNS(IP_PrimaryDNS); // optional
  IPAddress secondaryDNS(IP_SecondaryDNS); // optional

  WiFi.mode(WIFI_STA);

  if (!WiFi.config(local_IP, gateway, subnet, primaryDNS, secondaryDNS)) {
    Serial.println(F("STA Failed to configure"));
    major_fail();
  }

  //WiFi.setSleep(false);  // turn off wifi power saving, makes response MUCH faster
  
  WiFi.printDiag(Serial);

  WiFi.begin(ssid, password);
  while (WiFi.status() != WL_CONNECTED ) {
    delay(500);
    Serial.print(".");
    if (connAttempts > 10) {
      Serial.println(F("Cannot connect"));
      WiFi.printDiag(Serial);
      major_fail();
      return false;
    }
    connAttempts++;
  }
  return true;
}


//~~~~~~~~~~~~~~~~~~~~~~~~~~~~~~~~~~~~~~~~~~~~~~~~~~~~~~~~~~~~~~~~~~~~~~~~~~~~~~~~~
//
// 

void init_time() {

  sntp_setoperatingmode(SNTP_OPMODE_POLL);
  sntp_setservername(0, "pool.ntp.org");
  sntp_setservername(1, "time.windows.com");
  sntp_setservername(2, "time.nist.gov");

  sntp_init();

  // wait for time to be set
  time_t now = 0;
  timeinfo = { 0 };
  int retry = 0;
  const int retry_count = 10;
  while (timeinfo.tm_year < (2016 - 1900) && ++retry < retry_count) {
    Serial.printf("Waiting for system time to be set... (%d/%d) -- %d\n", retry, retry_count, timeinfo.tm_year);
    delay(2000);
    time(&now);
    localtime_r(&now, &timeinfo);
    Serial.println(ctime(&now));
  }

  if (timeinfo.tm_year < (2016 - 1900)) {
    major_fail();
  }
}


//~~~~~~~~~~~~~~~~~~~~~~~~~~~~~~~~~~~~~~~~~~~~~~~~~~~~~~~~~~~~~~~~~~~~~~~~~~~~~~~~~
//
// GPIO stuff for battery voltage reads
//

#include "esp_adc_cal.h"
#define DEFAULT_VREF    1100        //Use adc2_vref_to_gpio() to obtain a better estimate
#define NO_OF_SAMPLES   64          //Multisampling
static esp_adc_cal_characteristics_t *adc_chars;

uint32_t batteryVoltage;    
char batteryMsg[35];  

void Configure_GPIO12() {  // GPIO12 is shared with the SD card - no SD, no worries
  //Configure GPIO12 for ADC to read battery voltage
  adc2_config_channel_atten(ADC2_GPIO12_CHANNEL, ADC_ATTEN_11db);
    
  //Characterize ADC
  adc_chars = (esp_adc_cal_characteristics_t*) calloc(1, sizeof(esp_adc_cal_characteristics_t));
  esp_adc_cal_value_t val_type = esp_adc_cal_characterize(ADC_UNIT_2, ADC_ATTEN_11db, ADC_WIDTH_12Bit, DEFAULT_VREF, adc_chars);
}

uint32_t Get_GPIO12_Voltage() {
  // note: when the wifi is on, GPIO12 returns 0. If wifi is needed, turn wifi off, 
  // get the reading, then turn wifi on again.
  
  //Multisampling - average 64 samples to get best value
  uint32_t adc_reading = 0;
  for (int i = 0; i < NO_OF_SAMPLES; i++) {
    int read_raw;
    adc2_get_raw(ADC2_GPIO12_CHANNEL, ADC_WIDTH_12Bit, &read_raw);
    adc_reading += read_raw;
  }
  adc_reading /= NO_OF_SAMPLES;

  //Convert adc_reading to voltage in mV
  uint32_t voltage = esp_adc_cal_raw_to_voltage(adc_reading, adc_chars);
  //Serial.print("Raw: ");
  //Serial.print(adc_reading);

  // Correct voltage value due to voltage divider circuit
  voltage = (voltage * 147) / 100;
  return voltage;
}


/**********************************************************************************
 * 
 *  From here to end comment below is the contents of sendemail.h
 *
 *  If an SD card is used, it is assumed to be mounted on /sdcard.
 * 
 */

#ifndef __SENDEMAIL_H
#define __SENDEMAIL_H

// uncomment for debug output on Serial port
//#define DEBUG_EMAIL_PORT

// uncomment if using SD card
#define USING_SD_CARD

#include <WiFiClient.h>
#include <WiFiClientSecure.h>
#include <base64.h>

#ifdef USING_SD_CARD
#include <FS.h>
#include "SD_MMC.h"
#endif


class SendEmail
{
  private:
    const String host;
    const int port;
    const String user;
    const String passwd;
    const int timeout;
    const bool ssl;
    WiFiClient* client;
    String readClient();

    // stuff for attaching buffers (could be images and videos held in memory)
    int attachbuffercount;  // current number of buffer attachments
    static const int attachbuffermaxcount = 10;  // max number of buffers that can be attached
    struct attachbufferitem {
      char * buffername;  // name for buffer
      char * buffer;  // pointer to buffer
      size_t buffersize;  // number of bytes in buffer
    };
    attachbufferitem attachbufferitems[attachbuffermaxcount];
    
#ifdef USING_SD_CARD
    // stuff for attaching files (assumes SD card is mounted as /sdcard)
    int attachfilecount;  // current number of file attachments
    static const int attachfilemaxcount = 10;  // max number of file that can be attached
    struct attachfileitem {
      char * filename;  // name for file
    };
    attachfileitem attachfileitems[attachfilemaxcount];
#endif
    
  public:
    SendEmail(const String& host, const int port, const String& user, const String& passwd, const int timeout, const bool ssl);

    void attachbuffer(char * name, char * bufptr, size_t bufsize);

    void attachfile(char * name);
    
    bool send(const String& from, const String& to, const String& subject, const String& msg);

    void close();
};

#endif

/* end of sendemail.h */


SemaphoreHandle_t baton;

//~~~~~~~~~~~~~~~~~~~~~~~~~~~~~~~~~~~~~~~~~~~~~~~~~~~~~~~~~~~~~~~~~~~~~~~~~~~~~~~~~
//
//  do_fb - just takes a picture and discards it
//
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
void loop() {
  
  if ( millis() - timeout_10min > (10 * 60 * 1000) ) {       // 10 minutes
    do_deep_sleep();
  }

  if ( emailvideostatus == 1 ) {  // takes too long to keep in uri handler so doing it here
    static char sub[30];
    strcpy( sub, "Camera Event" );
    static char msg[120];
    strcpy( msg, "Manual trigger, please see attached video\n" );
    strcat( msg, batteryMsg );

    //Serial.print(F("in EmailVideoTask, Heap is: ")); Serial.println(ESP.getFreeHeap());
  
    email_video( sub, msg );
    // after email_video emailvideostatus should be set to 2 or 3
  }
  
  delay(1000);
}


/*****************************************************************************
 * 
 *  From here to the end is the contents of sendemail.cpp
 *  This version can send text or binary objects (jpg, avi) from memory as attachments
 *  and can send files from the SD card mounted on /sdcard.
 *  
 *  *** Uncomment the #include if the below is moved back into sendemail.cpp ***
 *
 */

//#include "sendemail.h"

SendEmail::SendEmail(const String& host, const int port, const String& user, const String& passwd, const int timeout, const bool ssl) :
    host(host), port(port), user(user), passwd(passwd), timeout(timeout), ssl(ssl), client((ssl) ? new WiFiClientSecure() : new WiFiClient())
{
  attachbuffercount = 0;
#ifdef USING_SD_CARD
  attachfilecount = 0;
#endif
}

String SendEmail::readClient()
{
  String r = client->readStringUntil('\n');
  r.trim();
  while (client->available()) r += client->readString();
  return r;
}

void SendEmail::attachbuffer(char * name, char * bufptr, size_t bufsize)
{
  attachbufferitems[attachbuffercount].buffername = (char *) malloc( strlen(name)+1 );
  strcpy( attachbufferitems[attachbuffercount].buffername, name ); 
  attachbufferitems[attachbuffercount].buffer = bufptr;
  attachbufferitems[attachbuffercount].buffersize = bufsize;
  
  attachbuffercount++;
}

#ifdef USING_SD_CARD
void SendEmail::attachfile(char * name)
{
  attachfileitems[attachfilecount].filename = (char *) malloc( strlen(name)+8 );
  strcpy( attachfileitems[attachfilecount].filename, "/sdcard" );
  strcat( attachfileitems[attachfilecount].filename, name );
  
  attachfilecount++;
}
#endif


bool SendEmail::send(const String& from, const String& to, const String& subject, const String& msg)
{
  if (!host.length())
  {
    return false;
  }
  String buffer2((char *)0);
  buffer2.reserve(800);  // really should only use 780 of it
  client->stop();
  client->setTimeout(timeout);
  // smtp connect
#ifdef DEBUG_EMAIL_PORT
  Serial.print(F("Connecting: "));
  Serial.print(host);
  Serial.print(":");
  Serial.println(port);
#endif
  if (!client->connect(host.c_str(), port))
  {
    return false;
  }
  String buffer = readClient();
#ifdef DEBUG_EMAIL_PORT
  Serial.print(F("SERVER->CLIENT: "));
  Serial.println(buffer);
#endif
  // note: F(..) as used below puts the string in flash instead of RAM
  if (!buffer.startsWith(F("220")))
  {
    return false;
  }
  buffer = F("HELO ");
  buffer += client->localIP();
  client->println(buffer);
#ifdef DEBUG_EMAIL_PORT
  Serial.print(F("CLIENT->SERVER: "));
  Serial.println(buffer);
#endif
  buffer = readClient();
#ifdef DEBUG_EMAIL_PORT
  Serial.print(F("SERVER->CLIENT: "));
  Serial.println(buffer);
#endif
  if (!buffer.startsWith(F("250")))
  {
    return false;
  }
  if (user.length()>0  && passwd.length()>0 )
  {
    buffer = F("AUTH LOGIN");
    client->println(buffer);
#ifdef DEBUG_EMAIL_PORT
  Serial.print(F("CLIENT->SERVER: "));
  Serial.println(buffer);
#endif
    buffer = readClient();
#ifdef DEBUG_EMAIL_PORT
  Serial.print(F("SERVER->CLIENT: "));
  Serial.println(buffer);
#endif
    if (!buffer.startsWith(F("334")))
    {
      return false;
    }
    base64 b;
    buffer = user;
    buffer = b.encode(buffer);
    client->println(buffer);
#ifdef DEBUG_EMAIL_PORT
  Serial.print(F("CLIENT->SERVER: "));
  Serial.println(buffer);
#endif
    buffer = readClient();
#ifdef DEBUG_EMAIL_PORT
  Serial.print(F("SERVER->CLIENT: "));
  Serial.println(buffer);
#endif
    if (!buffer.startsWith(F("334")))
    {
      return false;
    }
    buffer = this->passwd;
    buffer = b.encode(buffer);
    client->println(buffer);
#ifdef DEBUG_EMAIL_PORT
  Serial.print(F("CLIENT->SERVER: "));
  Serial.println(buffer);
#endif
    buffer = readClient();
#ifdef DEBUG_EMAIL_PORT
  Serial.print(F("SERVER->CLIENT: "));
  Serial.println(buffer);
#endif
    if (!buffer.startsWith(F("235")))
    {
      return false;
    }
  }
  // smtp send mail
  buffer = F("MAIL FROM: ");
  buffer += from;
  client->println(buffer);
#ifdef DEBUG_EMAIL_PORT
  Serial.print(F("CLIENT->SERVER: "));
  Serial.println(buffer);
#endif
  buffer = readClient();
#ifdef DEBUG_EMAIL_PORT
  Serial.print(F("SERVER->CLIENT: "));
  Serial.println(buffer);
#endif
  if (!buffer.startsWith(F("250")))
  {
    return false;
  }
  buffer = F("RCPT TO: ");
  buffer += to;
  client->println(buffer);
#ifdef DEBUG_EMAIL_PORT
  Serial.print(F("CLIENT->SERVER: "));
  Serial.println(buffer);
#endif
  buffer = readClient();
#ifdef DEBUG_EMAIL_PORT
  Serial.print(F("SERVER->CLIENT: "));
  Serial.println(buffer);
#endif
  if (!buffer.startsWith(F("250")))
  {
    return false;
  }
  buffer = F("DATA");
  client->println(buffer);
#ifdef DEBUG_EMAIL_PORT
  Serial.print(F("CLIENT->SERVER: "));
  Serial.println(buffer);
#endif
  buffer = readClient();
#ifdef DEBUG_EMAIL_PORT
  Serial.print(F("SERVER->CLIENT: "));
  Serial.println(buffer);
#endif
  if (!buffer.startsWith(F("354")))
  {
    return false;
  }
  buffer = F("From: ");
  buffer += from;
  client->println(buffer);
#ifdef DEBUG_EMAIL_PORT
  Serial.print(F("CLIENT->SERVER: "));
  Serial.println(buffer);
#endif
  buffer = F("To: ");
  buffer += to;
  client->println(buffer);
#ifdef DEBUG_EMAIL_PORT
  Serial.print(F("CLIENT->SERVER: "));
  Serial.println(buffer);
#endif
  buffer = F("Subject: ");
  buffer += subject;
  client->println(buffer);
#ifdef DEBUG_EMAIL_PORT
  Serial.print(F("CLIENT->SERVER: "));
  Serial.println(buffer);
#endif
  // setup to send message body
  buffer = F("MIME-Version: 1.0\r\n");
  buffer += F("Content-Type: multipart/mixed; boundary=\"{BOUNDARY}\"\r\n\r\n");
  buffer += F("--{BOUNDARY}\r\n");
  buffer += F("Content-Type: text/plain\r\n");
  client->println(buffer);
#ifdef DEBUG_EMAIL_PORT
  Serial.print(F("CLIENT->SERVER: "));
  Serial.println(buffer);
#endif
  buffer = msg;
  client->println(buffer);
#ifdef DEBUG_EMAIL_PORT
  Serial.print(F("CLIENT->SERVER: "));
  Serial.println(buffer);
#endif
  // process buffer attachments
  for ( int i = 0; i < attachbuffercount; i++ ) {
    char * pos = attachbufferitems[i].buffer;
    size_t alen = attachbufferitems[i].buffersize;
    base64 b;
    
    buffer = F("\r\n--{BOUNDARY}\r\n");
    buffer += F("Content-Type: application/octet-stream\r\n");
    buffer += F("Content-Transfer-Encoding: base64\r\n");
    buffer += F("Content-Disposition: attachment;filename=\"");
    buffer += attachbufferitems[i].buffername;
    buffer += F("\"\r\n");
    client->println(buffer);
#ifdef DEBUG_EMAIL_PORT
  Serial.print(F("CLIENT->SERVER: "));
  Serial.println(buffer);
  size_t bytessent = 0;
#endif
    // read data from buffer, base64 encode and send it
    // 3 binary bytes (57) becomes 4 base64 bytes (76)
    // plus CRLF is ideal for one line of MIME data
    // 570 bytes will be read at a time and sent as ten lines of base64 data
    size_t flen = 570;  
    uint8_t * fdata = (uint8_t*) malloc( flen );
    if ( alen < flen ) flen = alen;
    // read data from buffer
    memcpy( fdata, pos, flen ); 
    delay(10);
    buffer2 = "";
    size_t bytecount = 0;
    while ( flen > 0 ) {
      while ( flen > 56 ) {
        // convert to base64 in 57 byte chunks
        buffer2 += b.encode( fdata+bytecount, 57 );
        // tack on CRLF
        buffer2 += "\r\n";
        bytecount += 57;
        flen -= 57;
      }
      if ( flen > 0 ) {
        // convert last set of bytes to base64
        buffer2 += b.encode( fdata+bytecount, flen );
        // tack on CRLF
        buffer2 += "\r\n";
      }
      // send the lines in buffer
      client->println( buffer2 );
#ifdef DEBUG_EMAIL_PORT
  bytessent += bytecount + flen;
  Serial.print(F(" bytes sent so far: ")); Serial.println(bytessent);
#endif
      buffer2 = "";
      delay(10);
      // calculate bytes left to send
      alen = alen - bytecount - flen;
      pos = pos + bytecount + flen;
      flen = 570;
      if ( alen < flen ) flen = alen;
      // read data from buffer
      if ( flen > 0 ) memcpy( fdata, pos, flen ); 
      bytecount = 0;
    }
    free( fdata );
    fdata = NULL;
  }
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

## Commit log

2020-07-05 Update ESP32CamRemotePIR.ino
    This update includes a fix for the often seen Camera init failed with error 0x20004
    [ESP32CamRemotePIR.ino]
2020-11-09 Update ESP32CamRemotePIR.ino
    Changed frames per second from 8 to 10.
2022-04-01 Update ESP32CamRemotePIR.ino
    Updated to start deep sleep only after PIR action has ended.
2022-04-29 Attempt to improve PIR interface to ESP32CAM
2023-03-18 Added STL files for 3D printing an enclosure.
    [ESP32CAM_Box_PIR_Battery.stl, ESP32CAM_Box_PIR_Battery_Base.stl, ESP32CAM_Box_PIR_Battery_Cover.stl]
